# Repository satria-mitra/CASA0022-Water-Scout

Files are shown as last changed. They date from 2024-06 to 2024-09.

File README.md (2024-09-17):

<h1 align="center">Water Scout: A LoRaWAN-Based Water Height Monitoring and Visualization System for Urban Waterways</h1>

A dissertation for an [MSc Connected Environments](https://www.ucl.ac.uk/prospective-students/graduate/taught-degrees/connected-environments-msc)
<p>Centre for Advanced Spatial Analysis, Bartlett Faculty of the Built Environment</p>
<p>University College London </p>

##

This project utilised an Arduino 1310 with LoRaWAN communication and Ultrasonic sensor to monitor the water level of the River Lea that flows below the House Mill. The data observed then transmitted to The Things Network and published to MQTT Client. A 3D visualisation web page using WebXR was built to display the water level of The House Mill in 3D scene. The House Mill was created by [Dr. Gai Jorayev ](https://www.ucl.ac.uk/archaeology/people/gai-jorayev) and published on [Sketchfab](https://sketchfab.com/3d-models/house-mill-in-2019-c87dd07ab29f474aa491c88bc6b4956f). [The 3D visualisations web page](https://casa-0022-water-scout.vercel.app/) was hosted in the cloud for accessibility

| Water Scout | 3D Visualisations |
| :---: | :---: |
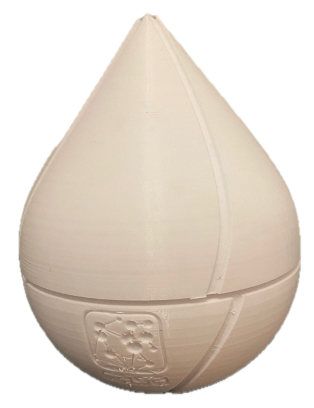
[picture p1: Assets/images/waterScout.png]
Water Scout device
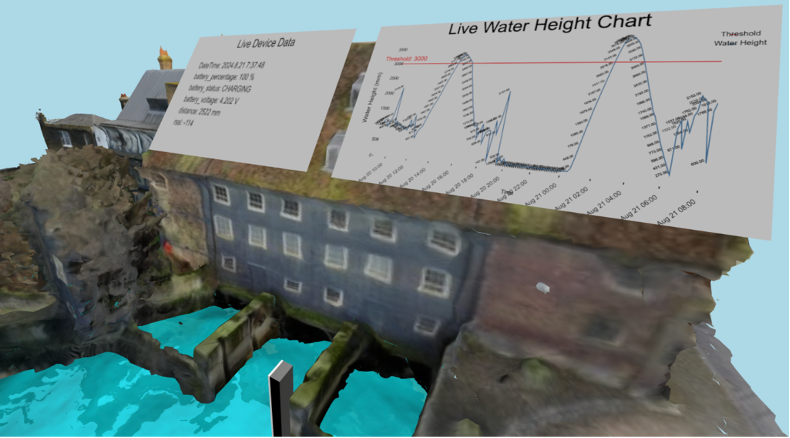
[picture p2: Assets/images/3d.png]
3D Visualisations
|  |  |

## Repository Content Summary

1. **3D Parts**

   This folder includes the 3D printed parts, namely Fusion360 project files and STLs for the enclosures and the 3D objects for the Data Table.

   - [Water Scout Enclosure](</3D Parts/Enclosure>)
   - [Solar Panel](</3D Parts/Solar Panel/>)

2. **Arduino**

   Includes code during calibration mode, and Water Scout device

   - [DYP-A01](/Arduino/DYP-A01)

3. **Schematics**

   The final schematics including PCB Gerber file used for this project. 
   
4. **Docs**

   This folder holds the page for the Water Scout web pages, including device introduction, 3D Visualisation page and VR mode for Connected Environment exhibition

5. **Dashboard**

   The configuration file for Node Red, Influxdb and Grafana 

6. **Supporting Documents**

   The extra files from the dissertation report, including Lab Testing, Deployment Test, and analysis

## Project Overview

<p align="center">Final prototype</p>

<p align="center">

</p>

## Building

### Used components and tools

Hardware:

* [Arduino MKR WAN 1310](https://docs.arduino.cc/hardware/mkr-wan-1310): microcontroller with LoRa connectivity.
* [DYP-A01](https://www.dypcn.com/high-performance-ultrasonic-precision-rangefinder-dyp-a01-product/): a weatherproof humidity and temperature sensor.
* [Adafruit Solar Charger](https://www.adafruit.com/product/4755): a solar charger module
* [Adafruit Lipo Battery Gauge](https://www.adafruit.com/product/5580)
* [Solar panel](https://coolcomponents.co.uk/products/solar-panel-1-watt): 1 Watt, 10x80 cm.
* 2000 mA 3.7v battery

Software:

 - [InfluxDB](https://www.influxdata.com/)
 - [Telegraf](https://www.influxdata.com/time-series-platform/telegraf/)
 - [Grafana](https://grafana.com/)
 - [Docker Compose](https://docs.docker.com/compose/)

All the software applications are packed into one using Docker

## Results

#### The 3D Visualisations

<p align="center">3D Visualisations scene</p>

<p align="center">

</p>

Click here for [3D Visualisations](https://casa-0022-water-scout.vercel.app/visualisation.html)

#### VR Mode for exhibition

<p align="center">3D Visualisations scene</p>

<p align="center">

</p>

Click here for [VR Mode](https://casa-0022-water-scout.vercel.app/arjs.html)

## Credits

This project was built with inspiration and support from several open-source projects and contributions.

Special thanks to [CASA CE](https://github.com/ucl-casa-ce) team especially for the [Artes](https://github.com/ucl-casa-ce/artes) repository which was instrumental in creating the VR mode for the Water Scout project. Portions of the code for the VR mode were adapted and modified from his project.

Additionally, thanks to the open-source communities and contributors behind the following software and tools, which were essential in the development of this project:

- Arduino
- The Things Network
- InfluxDB
- Grafana
- Docker

## License

###### The software side is licensed under MIT License

```
MIT License

Permission is hereby granted, free of charge, to any person obtaining a copy
of this software and associated documentation files (the "Software"), to deal
in the Software without restriction, including without limitation the rights
to use, copy, modify, merge, publish, distribute, sublicense, and/or sell
copies of the Software, and to permit persons to whom the Software is
furnished to do so, subject to the following conditions:

The above copyright notice and this permission notice shall be included in all
copies or substantial portions of the Software.

THE SOFTWARE IS PROVIDED "AS IS", WITHOUT WARRANTY OF ANY KIND, EXPRESS OR
IMPLIED, INCLUDING BUT NOT LIMITED TO THE WARRANTIES OF MERCHANTABILITY,
FITNESS FOR A PARTICULAR PURPOSE AND NONINFRINGEMENT. IN NO EVENT SHALL THE
AUTHORS OR COPYRIGHT HOLDERS BE LIABLE FOR ANY CLAIM, DAMAGES OR OTHER
LIABILITY, WHETHER IN AN ACTION OF CONTRACT, TORT OR OTHERWISE, ARISING FROM,
OUT OF OR IN CONNECTION WITH THE SOFTWARE OR THE USE OR OTHER DEALINGS IN THE
SOFTWARE.
```

###### The hardware side is licensed under CERN License

```
This documentation describes Open Hardware and is licensed under the CERN OHL v. 1.2.

You may redistribute and modify this documentation under the terms of the CERN OHL v.1.2. (http://ohwr.org/cernohl). This documentation is distributed WITHOUT ANY EXPRESS OR IMPLIED WARRANTY, INCLUDING OF MERCHANTABILITY, SATISFACTORY QUALITY AND FITNESS FOR A PARTICULAR PURPOSE. Please see the CERN OHL v.1.2 for applicable conditions
```

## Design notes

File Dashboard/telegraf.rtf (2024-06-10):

# Telegraf Configuration

# Global settings - you don't need to edit these #

# Global tags can be specified here in key="value" format.

[global_tags]

# Configuration for telegraf agent

[agent]
## Default data collection interval for all inputs

## For the plant monitor demo you dont need to change any these settings

interval = "10s"
round_interval = true
metric_batch_size = 1000
metric_buffer_limit = 10000
collection_jitter = "0s"
flush_interval = "10s"
flush_jitter = "0s"
precision = ""
debug = false
quiet = false
logfile = ""
## Override default hostname, if empty use os.Hostname()

hostname = ""
## If set to true, do no set the "host" tag in the telegraf agent.

omit_hostname = false

# OUTPUT PLUGINS #

[[outputs.influxdb_v2]]
urls = ["http://127.0.0.1:8086"]
## Token for authentication.

token = "A9q1_9cbwyPD3nAienTWf8Uuuoo83Wz6qguXdMlR4iapjWbsfOyw_JCQZXwPrnQ2FdWYLl-OxhJSIwsnli-82A=="
## Organization is the name of the organization you wish to write to; must exist.

organization = "casa"
## Destination bucket to write into.

bucket = "rasp-pi"

[[outputs.influxdb_v2]]
urls = ["http://127.0.0.1:8086"]
## Token for authentication.

token = "A9q1_9cbwyPD3nAienTWf8Uuuoo83Wz6qguXdMlR4iapjWbsfOyw_JCQZXwPrnQ2FdWYLl-OxhJSIwsnli-82A=="
## Organization is the name of the organization you wish to write to; must exist.

organization = "casa"
## Destination bucket to write into.

bucket = "mqtt-data"

# INPUT PLUGINS #

# Read metrics about cpu usage

[[inputs.cpu]]
## Whether to report per-cpu stats or not

percpu = true
## Whether to report total system cpu stats or not

totalcpu = true
## If true, collect raw CPU time metrics.

collect_cpu_time = false
## If true, compute and report the sum of all non-idle CPU states.

report_active = false

[[inputs.disk]]
## By default stats will be gathered for all mount points.

## Set mount_points will restrict the stats to only the specified mount points.

# mount_points = ["/"]

## Ignore mount points by filesystem type.

ignore_fs = ["tmpfs", "devtmpfs", "devfs", "overlay", "aufs", "squashfs"]
[[inputs.diskio]]
[[inputs.mem]]
[[inputs.net]]
[[inputs.processes]]
[[inputs.swap]]
[[inputs.system]]

[[inputs.exec]]
commands = ["/usr/bin/vcgencmd measure_temp"]
name_override = "temperature_gpu"
data_format = "grok"
grok_patterns = ["%{NUMBER:value:float}"]

[[inputs.temp]]

# SERVICE INPUT PLUGINS #

# Read metrics from MQTT topic(s)

#THING NETWORK META DATA#

[[inputs.mqtt_consumer]]
alias = "thing_network_consumer"
name_override = "thing_network"
servers = ["tcp://eu1.cloud.thethings.network:1883"]
topics = ["#"]
max_undelivered_messages = 1

username = "${THING_USERNAME}"
password = "${THING_API_KEY}"
data_format = "json_v2"

[[inputs.mqtt_consumer.json_v2]]
[[inputs.mqtt_consumer.json_v2.tag]]
path = "@this.end_device_ids.device_id"

[[inputs.mqtt_consumer.json_v2.object]]
path = "end_device_ids"
disable_prepend_keys = true

[[inputs.mqtt_consumer.json_v2.object]]
path = "uplink_message"
disable_prepend_keys = true
excluded_keys = ["time", "timestamp"]

[[inputs.mqtt_consumer.json_v2.object]]
path = "uplink_message.rx_metadata"
disable_prepend_keys = true
excluded_keys = ["time", "timestamp"]

#PLANT BUDDY DATA#

[[inputs.mqtt_consumer]]
alias = "thing_network_consumer2"
name_override = "sensor_data"

servers = ["tcp://eu1.cloud.thethings.network:1883"]
topics = ["#"]

username = "${THING_USERNAME}"
password = "${THING_API_KEY}"

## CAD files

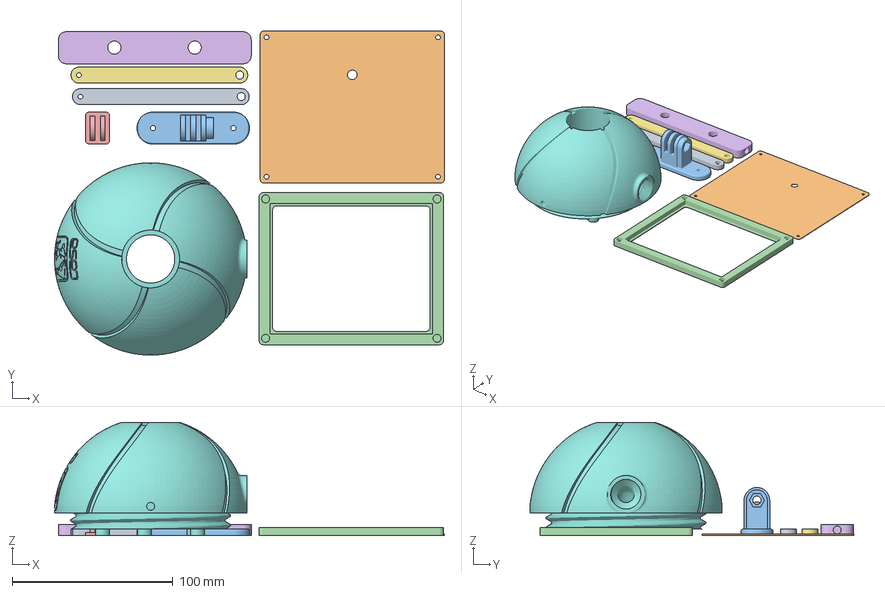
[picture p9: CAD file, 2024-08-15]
3D Parts/device.3mf
242.6 x 201.7 x 70.5 mm
arm.stl x 2
back_cover.stl
bracket_go_pro.stl
front_cover.stl
two_way_bracket.stl
bar.stl
bot_v3.stl

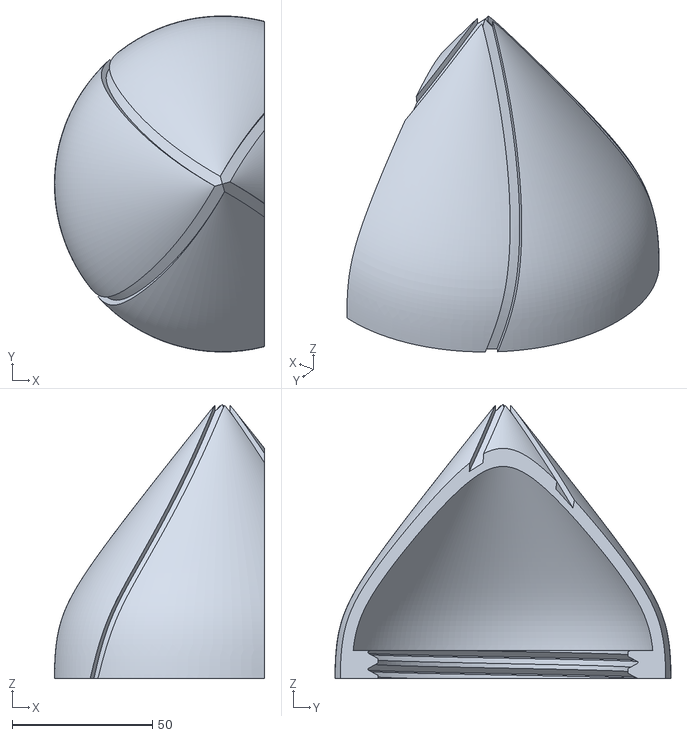
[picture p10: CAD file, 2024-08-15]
3D Parts/Encsloure/top_part_half.stl
74.8 x 119.6 x 97.5

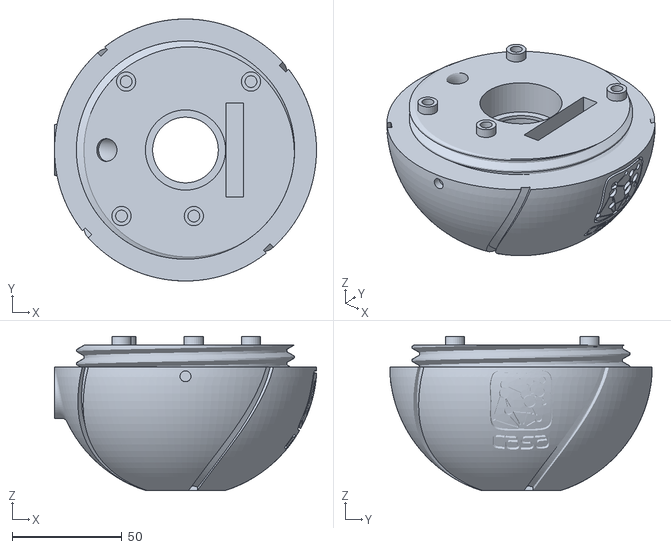
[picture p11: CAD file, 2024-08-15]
3D Parts/Encsloure/bot_v3.stl
119.6 x 119.6 x 70.5

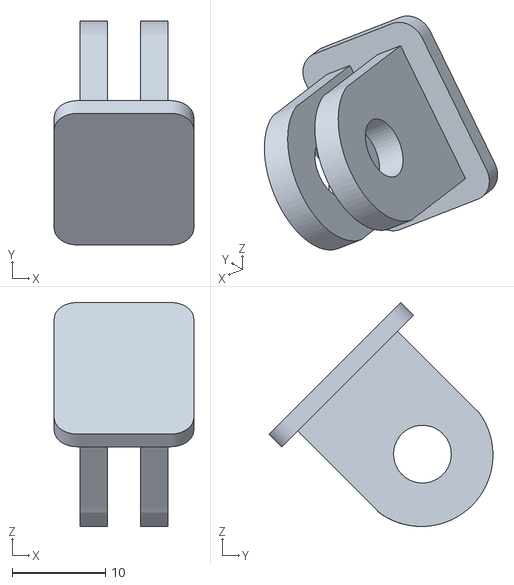
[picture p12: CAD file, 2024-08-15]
3D Parts/Solar Panel/Body1.stl
15.0 x 24.1 x 24.1

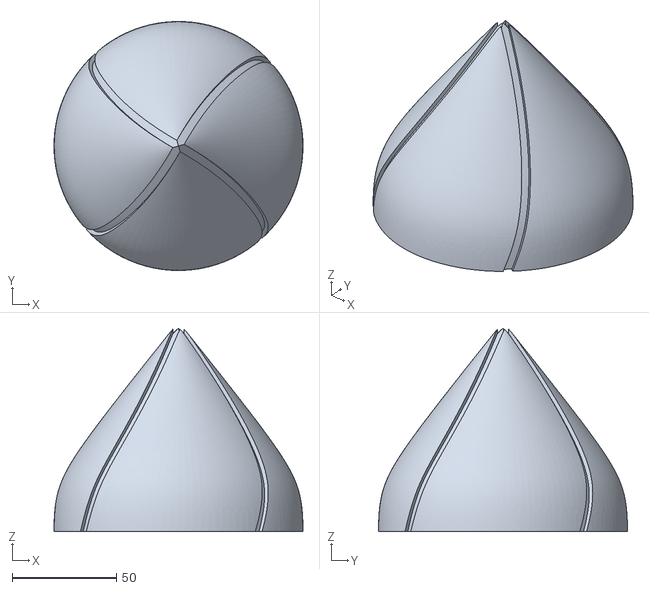
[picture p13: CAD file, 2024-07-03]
3D Parts/Encsloure/top_v2.stl
119.6 x 119.6 x 97.5

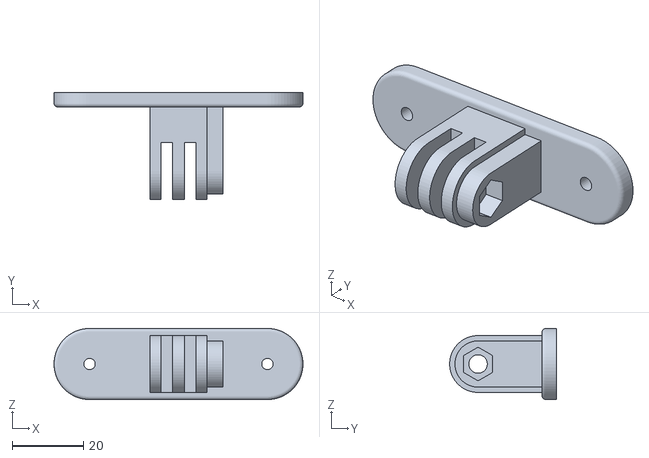
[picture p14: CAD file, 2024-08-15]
3D Parts/Solar Panel/bracket_go_pro.stl
70.0 x 30.0 x 20.0

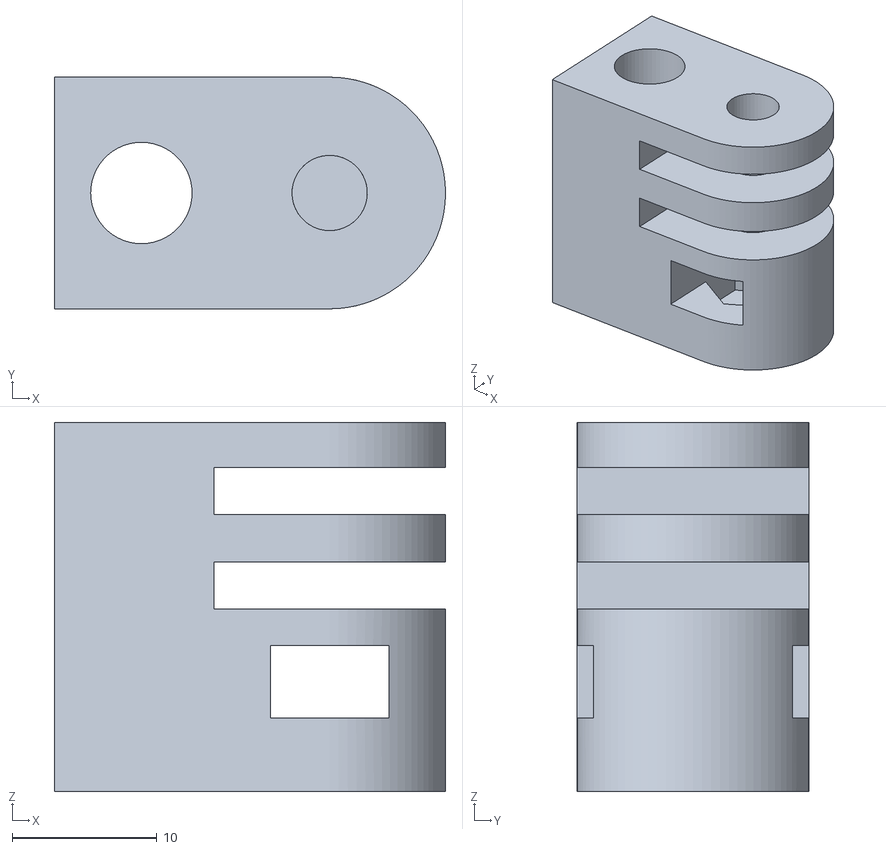
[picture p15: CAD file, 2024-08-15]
3D Parts/Solar Panel/solar_panel_trimount.stl
27.0 x 16.0 x 25.5

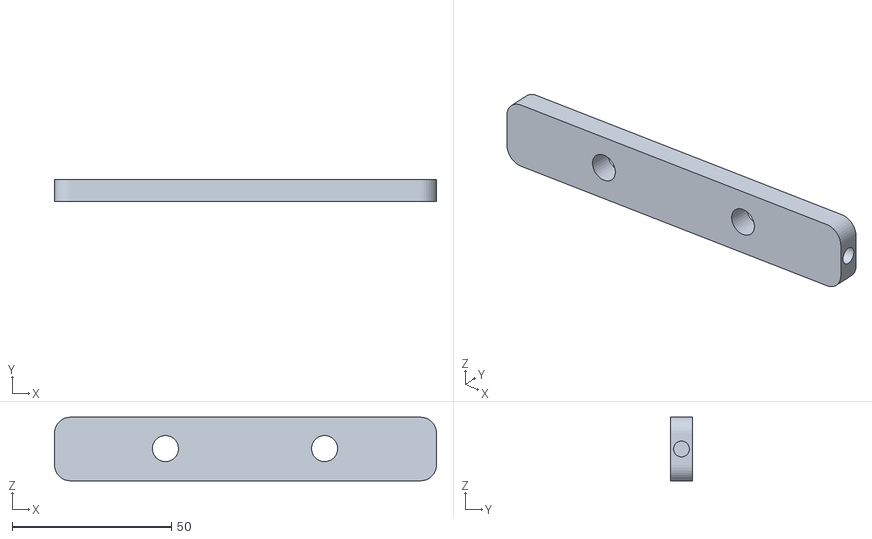
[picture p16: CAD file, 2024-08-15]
3D Parts/Solar Panel/bar.stl
120.0 x 7.00 x 20.0

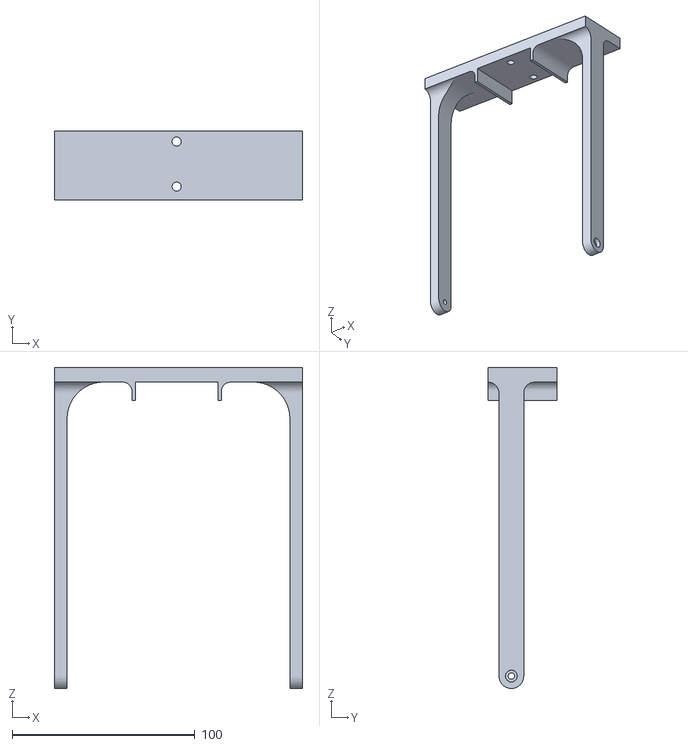
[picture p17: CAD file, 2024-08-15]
3D Parts/Solar Panel/device_bracket.stl
136.0 x 37.8 x 175.8

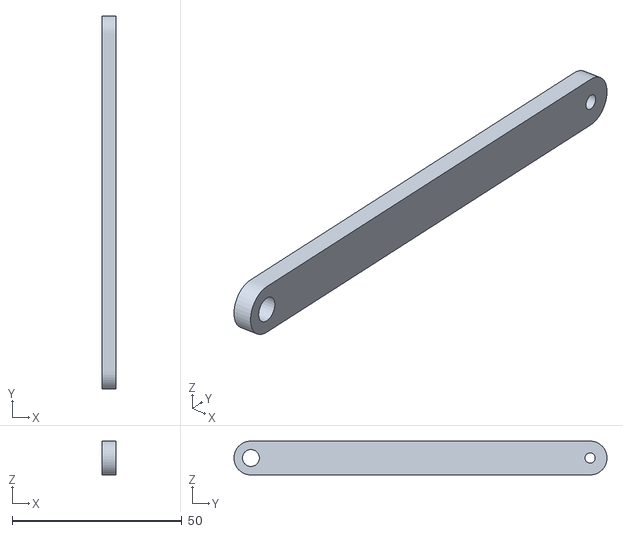
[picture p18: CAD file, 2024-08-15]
3D Parts/Solar Panel/arm.stl
4.00 x 110.0 x 10.0

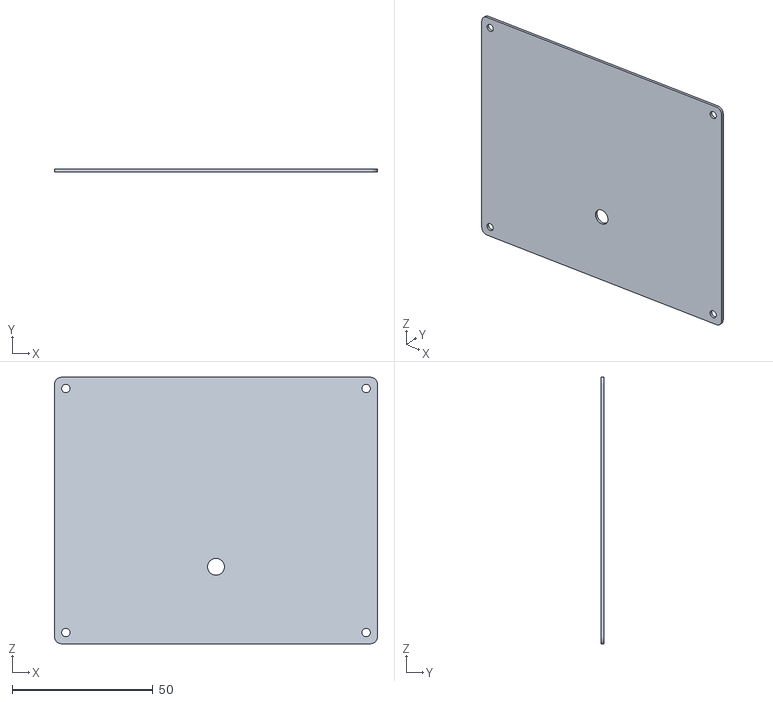
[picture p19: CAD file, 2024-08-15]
3D Parts/Solar Panel/back_cover.stl
114.7 x 1.00 x 94.7

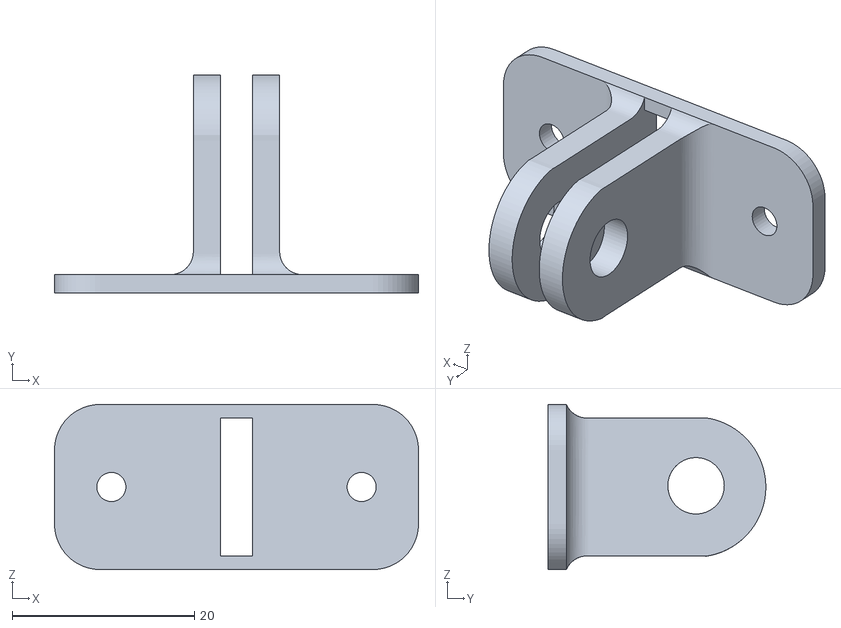
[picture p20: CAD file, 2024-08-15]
3D Parts/Solar Panel/back_bracket_v2.stl
40.0 x 23.9 x 18.1

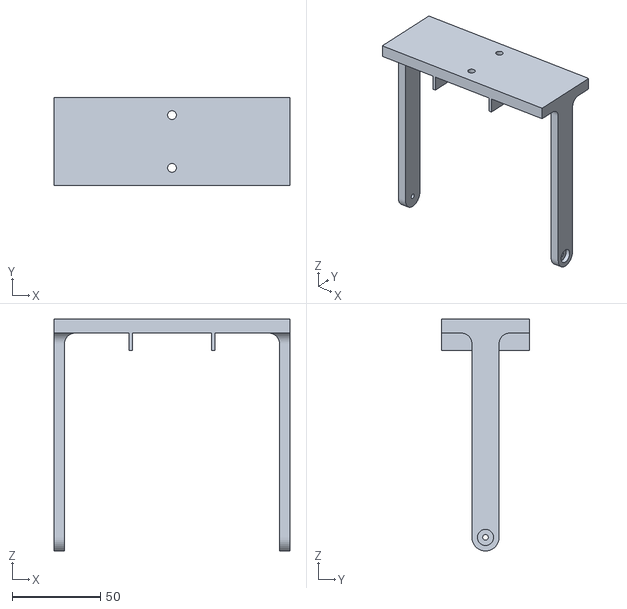
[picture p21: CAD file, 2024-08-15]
3D Parts/Solar Panel/device_arm.stl
134.0 x 50.0 x 131.7

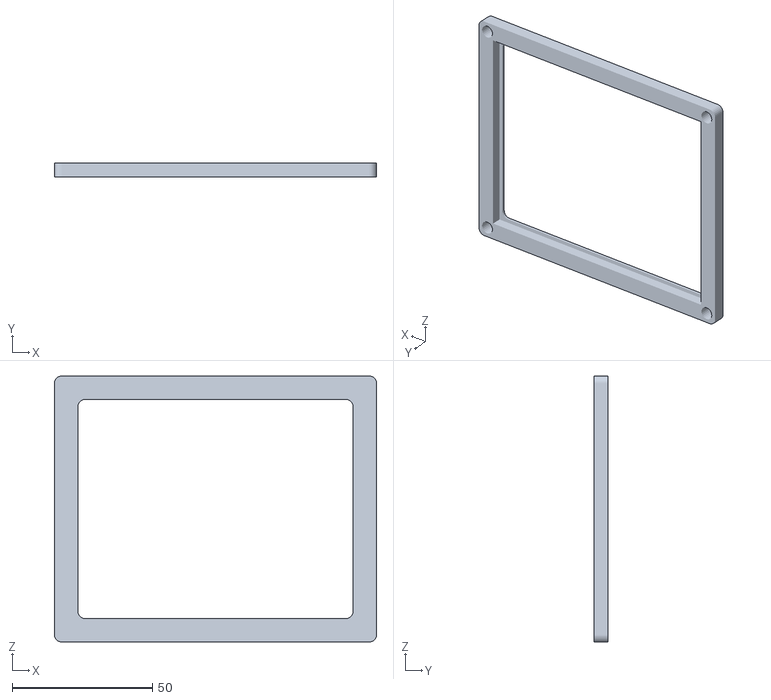
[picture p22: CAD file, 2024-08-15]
3D Parts/Solar Panel/front_cover.stl
114.7 x 5.00 x 94.7

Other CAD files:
3D Parts/Solar Panel/two_way_bracket.stl
3D Parts/Solar Panel/back_bracket v1.stl

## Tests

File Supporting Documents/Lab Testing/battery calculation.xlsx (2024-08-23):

State | Average Duration (seconds) | Average Current draws (mA) | Sum mA | Duty Cycle | Avg Consumption | 850 mAh Battery Life (days) | 1000 mAh Battery life (days) | 2000 mAh Battery Life (days)
Sensor Reading | 3 | 13 | 39 | 1 | 1.462 | 24.22 | 28.50 | 28.50
LoRA Transmitting | 4 | 5.34 | 21.36 | 5 | 0.696 | 50.91 | 59.90 | 59.90
LoRA Receiving | 1 | 1.16 | 1.16 | 10 | 0.600 | 59.05 | 69.47 | 69.47
Deep sleep Mode | 52 | 0.504 | 26.208 | 15 | 0.568 | 62.37 | 73.37 | 73.37
Sum | 60 |  | 87.728
Avg |  |  | 1.462133333
Sensor Reading | 3 | 13 | 39
LoRA Transmitting | 4 | 5.34 | 21.36
LoRA Receiving | 1 | 1.16 | 1.16
Deep sleep Mode | 292 | 0.504 | 147.168
Sum | 300 |  | 208.688
Avg |  |  | 0.6956266667
Sensor Reading | 3 | 13 | 39
LoRA Transmitting | 4 | 5.34 | 21.36
LoRA Receiving | 1 | 1.16 | 1.16
Deep sleep Mode | 592 | 0.504 | 298.368
 | 600 |  | 359.888
 |  |  | 0.5998133333
Sensor Reading | 3 | 13 | 39
LoRA Transmitting | 4 | 5.34 | 21.36
LoRA Receiving | 1 | 1.16 | 1.16
Deep sleep Mode | 892 | 0.504 | 449.568
 | 900 |  | 511.088
 |  |  | 0.5678755556

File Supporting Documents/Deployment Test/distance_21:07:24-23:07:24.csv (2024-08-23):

Time | distance
21/07/24 04:10 | 1800
21/07/24 04:20 | 1800
21/07/24 04:30 | 1780
21/07/24 04:40 | 1800
21/07/24 04:50 | 1800
21/07/24 05:00 | 1773
21/07/24 05:10 | 1647
21/07/24 05:20 | 1532
21/07/24 05:30 | 1438
21/07/24 05:40 | 1401
21/07/24 05:50 | 1409
21/07/24 06:00 | 1465
21/07/24 06:10 | 1530
21/07/24 06:20 | 1635
21/07/24 06:30 | 1778
21/07/24 06:40 | 1789
21/07/24 06:50 | 1790
21/07/24 07:00 | 1795
21/07/24 07:10 | 1774
21/07/24 07:20 | 1790
21/07/24 07:30 | 1799
21/07/24 07:40 | 1796
21/07/24 07:50 | 1788
21/07/24 08:00 | 1773
21/07/24 08:10 | 1782
21/07/24 08:20 | 1785
21/07/24 08:30 | 1776
21/07/24 08:40 | 1792
21/07/24 08:50 | 1778
21/07/24 09:00 | 1777
21/07/24 09:10 | 1783
21/07/24 09:20 | 1800
21/07/24 09:35 | 1775
21/07/24 09:40 | 1781
21/07/24 09:50 | 1774
21/07/24 10:00 | 1798
21/07/24 10:10 | 1793
21/07/24 10:20 | 1780
21/07/24 10:30 | 1775
21/07/24 10:40 | 1770
21/07/24 10:50 | 1790
21/07/24 11:00 | 1785
21/07/24 11:10 | 1788
21/07/24 11:20 | 1781
21/07/24 11:30 | 1778
21/07/24 11:40 | 1794
21/07/24 11:50 | 1782
21/07/24 12:00 | 1786
21/07/24 12:15 | 1777
21/07/24 12:20 | 1773
21/07/24 12:30 | 1800
21/07/24 12:40 | 1777
21/07/24 12:50 | 1796
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

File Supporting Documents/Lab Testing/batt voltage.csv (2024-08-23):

Time | battery_voltage
07/06/2024 16:00 | 4.198
07/06/2024 16:10 | 4.197
07/06/2024 16:20 | 4.197
07/06/2024 16:30 | 4.197
07/06/2024 16:40 | 4.197
07/06/2024 16:50 | 4.197
07/06/2024 17:00 | 4.196
07/06/2024 17:10 | 4.196
07/06/2024 17:20 | 4.197
07/06/2024 17:30 | 4.195
07/06/2024 17:40 | 4.197
07/06/2024 17:50 | 4.193
07/06/2024 18:00 | 4.196
07/06/2024 18:10 | 4.197
07/06/2024 18:20 | 4.195
07/06/2024 18:30 | 4.197
07/06/2024 18:40 | 4.197
07/06/2024 18:50 | 4.197
07/06/2024 19:00 | 4.197
07/06/2024 19:10 | 4.195
07/06/2024 19:20 | 4.196
07/06/2024 19:30 | 4.196
07/06/2024 19:40 | 4.193
07/06/2024 19:50 | 4.196
07/06/2024 20:00 | 4.196
07/06/2024 20:10 | 4.196
07/06/2024 20:20 | 4.195
07/06/2024 20:30 | 4.195
07/06/2024 20:40 | 4.193
07/06/2024 20:50 | 4.195
07/06/2024 21:00 | 4.195
07/06/2024 21:10 | 4.193
07/06/2024 21:20 | 4.193
07/06/2024 21:30 | 4.195
07/06/2024 21:40 | 4.193
07/06/2024 21:50 | 4.193
07/06/2024 22:00 | 4.193
07/06/2024 22:10 | 4.195
07/06/2024 22:20 | 4.196
07/06/2024 22:30 | 4.196
07/06/2024 22:40 | 4.197
07/06/2024 22:50 | 4.197
07/06/2024 23:00 | 4.198
07/06/2024 23:10 | 4.2
07/06/2024 23:20 | 4.202
07/06/2024 23:30 | 4.201
07/06/2024 23:40 | 4.2
07/06/2024 23:50 | 4.2
08/06/2024 00:00 | 4.2
08/06/2024 00:10 | 4.198
08/06/2024 00:20 | 4.198
08/06/2024 00:30 | 4.2
08/06/2024 00:40 | 4.2
08/06/2024 00:50 | 4.198
08/06/2024 01:00 | 4.2
08/06/2024 01:10 | 4.2
08/06/2024 01:20 | 4.198
08/06/2024 01:30 | 4.201
08/06/2024 01:40 | 4.198
08/06/2024 01:50 | 4.2
08/06/2024 02:00 | 4.198
08/06/2024 02:10 | 4.2
08/06/2024 02:20 | 4.2
08/06/2024 02:30 | 4.197
08/06/2024 02:40 | 4.2
08/06/2024 02:50 | 4.2
08/06/2024 03:00 | 4.198
08/06/2024 03:10 | 4.2
08/06/2024 03:20 | 4.2
08/06/2024 03:30 | 4.2
08/06/2024 03:40 | 4.198
08/06/2024 03:50 | 4.2
08/06/2024 04:00 | 4.198
08/06/2024 04:10 | 4.2
08/06/2024 04:20 | 4.2
08/06/2024 04:30 | 4.198
08/06/2024 04:40 | 4.2
08/06/2024 04:50 | 4.2
08/06/2024 05:00 | 4.2
08/06/2024 05:10 | 4.2
08/06/2024 05:20 | 4.198
08/06/2024 05:30 | 4.198
08/06/2024 05:40 | 4.198
08/06/2024 05:50 | 4.197
08/06/2024 06:00 | 4.197
08/06/2024 06:10 | 4.198
08/06/2024 06:20 | 4.2
08/06/2024 06:30 | 4.198
08/06/2024 06:40 | 4.198
08/06/2024 06:50 | 4.201
08/06/2024 07:00 | 4.2
08/06/2024 07:10 | 4.198
08/06/2024 07:20 | 4.2
08/06/2024 07:30 | 4.2
08/06/2024 07:40 | 4.198
08/06/2024 07:50 | 4.198
08/06/2024 08:00 | 4.2
08/06/2024 08:10 | 4.197
08/06/2024 08:20 | 4.2
08/06/2024 08:30 | 4.198
08/06/2024 08:40 | 4.2
08/06/2024 08:50 | 4.2
08/06/2024 09:00 | 4.198
08/06/2024 09:10 | 4.2
08/06/2024 09:20 | 4.2
08/06/2024 09:30 | 4.201
08/06/2024 09:40 | 4.2
08/06/2024 09:50 | 4.2
08/06/2024 10:00 | 4.201
08/06/2024 10:10 | 4.201
08/06/2024 10:20 | 4.201
08/06/2024 10:30 | 4.201
08/06/2024 10:40 | 4.202
08/06/2024 10:50 | 4.201
08/06/2024 11:00 | 4.2
08/06/2024 11:10 | 4.2
08/06/2024 11:20 | 4.2
08/06/2024 11:30 | 4.2
08/06/2024 11:40 | 4.198
08/06/2024 11:50 | 4.2
08/06/2024 12:00 | 4.201
08/06/2024 12:10 | 4.198
08/06/2024 12:20 | 4.198
08/06/2024 12:30 | 4.2
08/06/2024 12:40 | 4.196
08/06/2024 12:50 | 4.198
08/06/2024 13:00 | 4.198
08/06/2024 13:10 | 4.197
08/06/2024 13:20 | 4.2
08/06/2024 13:30 | 4.197
08/06/2024 13:40 | 4.2
08/06/2024 13:50 | 4.198
08/06/2024 14:00 | 4.2
08/06/2024 14:10 | 4.197
08/06/2024 14:20 | 4.2
08/06/2024 14:30 | 4.196
08/06/2024 14:40 | 4.198
08/06/2024 14:50 | 4.198
08/06/2024 15:00 | 4.197
08/06/2024 15:10 | 4.198
08/06/2024 15:20 | 4.198
08/06/2024 15:30 | 4.198
08/06/2024 15:40 | 4.197
08/06/2024 15:50 | 4.198
08/06/2024 16:00 | 4.197
08/06/2024 16:10 | 4.197
08/06/2024 16:20 | 4.193
08/06/2024 16:30 | 4.198
08/06/2024 16:40 | 4.198
08/06/2024 16:50 | 4.198
08/06/2024 17:00 | 4.196
08/06/2024 17:10 | 4.197
08/06/2024 17:20 | 4.198
08/06/2024 17:30 | 4.196
08/06/2024 17:40 | 4.197
08/06/2024 17:50 | 4.196
08/06/2024 18:00 | 4.197
08/06/2024 18:10 | 4.192
08/06/2024 18:20 | 4.196
08/06/2024 18:30 | 4.196
08/06/2024 18:40 | 4.197
08/06/2024 18:50 | 4.197
08/06/2024 19:00 | 4.195
08/06/2024 19:10 | 4.195
08/06/2024 19:20 | 4.196
08/06/2024 19:30 | 4.196
08/06/2024 19:40 | 4.195
08/06/2024 19:50 | 4.196
08/06/2024 20:00 | 4.19
08/06/2024 20:10 | 4.196
08/06/2024 20:20 | 4.195
08/06/2024 20:30 | 4.195
08/06/2024 20:40 | 4.196
08/06/2024 20:50 | 4.196
08/06/2024 21:00 | 4.195
08/06/2024 21:10 | 4.195
08/06/2024 21:20 | 4.195
08/06/2024 21:30 | 4.193
08/06/2024 21:40 | 4.195
08/06/2024 21:50 | 4.192
08/06/2024 22:00 | 4.195
08/06/2024 22:10 | 4.195
08/06/2024 22:20 | 4.195
08/06/2024 22:30 | 4.197
08/06/2024 22:40 | 4.196
08/06/2024 22:50 | 4.198
08/06/2024 23:00 | 4.197
08/06/2024 23:10 | 4.198
08/06/2024 23:20 | 4.2
08/06/2024 23:30 | 4.201
08/06/2024 23:40 | 4.197
08/06/2024 23:50 | 4.201
09/06/2024 00:00 | 4.201
09/06/2024 00:10 | 4.2
09/06/2024 00:20 | 4.2
09/06/2024 00:30 | 4.201
09/06/2024 00:40 | 4.197
09/06/2024 00:50 | 4.198
09/06/2024 01:00 | 4.197
09/06/2024 01:10 | 4.2
09/06/2024 01:20 | 4.198
09/06/2024 01:30 | 4.197
09/06/2024 01:40 | 4.201
09/06/2024 01:50 | 4.2
09/06/2024 02:00 | 4.2
09/06/2024 02:10 | 4.201
09/06/2024 02:20 | 4.2
09/06/2024 02:30 | 4.198
09/06/2024 02:40 | 4.2
09/06/2024 02:50 | 4.2
09/06/2024 03:00 | 4.198
09/06/2024 03:10 | 4.2
09/06/2024 03:20 | 4.201
09/06/2024 03:30 | 4.2
09/06/2024 03:40 | 4.198
09/06/2024 03:50 | 4.2
09/06/2024 04:00 | 4.2
09/06/2024 04:10 | 4.198
09/06/2024 04:20 | 4.2
09/06/2024 04:30 | 4.2
09/06/2024 04:40 | 4.198
09/06/2024 04:50 | 4.2
09/06/2024 05:00 | 4.198
09/06/2024 05:10 | 4.2
09/06/2024 05:20 | 4.2
09/06/2024 05:30 | 4.2
09/06/2024 05:40 | 4.198
09/06/2024 05:50 | 4.198
09/06/2024 06:00 | 4.2
09/06/2024 06:10 | 4.198
09/06/2024 06:20 | 4.197
09/06/2024 06:30 | 4.198
09/06/2024 06:40 | 4.2
09/06/2024 06:50 | 4.2
09/06/2024 07:00 | 4.198
09/06/2024 07:10 | 4.198
09/06/2024 07:20 | 4.2
09/06/2024 07:30 | 4.2
09/06/2024 07:40 | 4.2
09/06/2024 07:50 | 4.2
09/06/2024 08:00 | 4.198
09/06/2024 08:10 | 4.201
09/06/2024 08:20 | 4.198
09/06/2024 08:30 | 4.201
09/06/2024 08:40 | 4.198
09/06/2024 08:50 | 4.2
09/06/2024 09:00 | 4.2
09/06/2024 09:10 | 4.2
09/06/2024 09:20 | 4.2
09/06/2024 09:30 | 4.201
09/06/2024 09:40 | 4.2
09/06/2024 09:50 | 4.201
09/06/2024 10:00 | 4.2
09/06/2024 10:10 | 4.198
09/06/2024 10:20 | 4.2
09/06/2024 10:30 | 4.2
09/06/2024 10:40 | 4.202
09/06/2024 10:50 | 4.201
09/06/2024 11:00 | 4.202
09/06/2024 11:10 | 4.201
09/06/2024 11:20 | 4.201
09/06/2024 11:30 | 4.2
09/06/2024 11:40 | 4.201
09/06/2024 11:50 | 4.201
09/06/2024 12:00 | 4.201
09/06/2024 12:10 | 4.2
09/06/2024 12:20 | 4.198
09/06/2024 12:30 | 4.198
09/06/2024 12:40 | 4.198
09/06/2024 12:50 | 4.2
09/06/2024 13:00 | 4.198
09/06/2024 13:10 | 4.197
09/06/2024 13:20 | 4.198
09/06/2024 13:30 | 4.198
09/06/2024 13:40 | 4.198
09/06/2024 13:50 | 4.195
09/06/2024 14:00 | 4.198
09/06/2024 14:10 | 4.198
09/06/2024 14:20 | 4.198
09/06/2024 14:30 | 4.197
09/06/2024 14:40 | 4.198
09/06/2024 14:50 | 4.2
09/06/2024 15:00 | 4.198
09/06/2024 15:10 | 4.197
09/06/2024 15:20 | 4.198
09/06/2024 15:30 | 4.197
09/06/2024 15:40 | 4.192
09/06/2024 15:50 | 4.197

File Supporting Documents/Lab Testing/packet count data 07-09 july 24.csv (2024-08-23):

Time | packet_count
07/06/2024 16:00 | 23
07/06/2024 16:10 | 24
07/06/2024 16:20 | 25
07/06/2024 16:30 | 26
07/06/2024 16:40 | 27
07/06/2024 16:50 | 28
07/06/2024 17:00 | 29
07/06/2024 17:10 | 30
07/06/2024 17:20 | 31
07/06/2024 17:30 | 32
07/06/2024 17:40 | 33
07/06/2024 17:50 | 34
07/06/2024 18:00 | 35
07/06/2024 18:10 | 36
07/06/2024 18:20 | 37
07/06/2024 18:30 | 38
07/06/2024 18:40 | 39
07/06/2024 18:50 | 40
07/06/2024 19:00 | 41
07/06/2024 19:10 | 42
07/06/2024 19:20 | 43
07/06/2024 19:30 | 44
07/06/2024 19:40 | 45
07/06/2024 19:50 | 46
07/06/2024 20:00 | 47
07/06/2024 20:10 | 48
07/06/2024 20:20 | 49
07/06/2024 20:30 | 50
07/06/2024 20:40 | 51
07/06/2024 20:50 | 52
07/06/2024 21:00 | 53
07/06/2024 21:10 | 54
07/06/2024 21:20 | 55
07/06/2024 21:30 | 56
07/06/2024 21:40 | 57
07/06/2024 21:50 | 58
07/06/2024 22:00 | 59
07/06/2024 22:10 | 60
07/06/2024 22:20 | 61
07/06/2024 22:30 | 62
07/06/2024 22:40 | 63
07/06/2024 22:50 | 64
07/06/2024 23:00 | 65
07/06/2024 23:10 | 66
07/06/2024 23:20 | 67
07/06/2024 23:30 | 68
07/06/2024 23:40 | 69
07/06/2024 23:50 | 70
08/06/2024 00:00 | 71
08/06/2024 00:10 | 72
08/06/2024 00:20 | 73
08/06/2024 00:30 | 74
08/06/2024 00:40 | 75
08/06/2024 00:50 | 76
08/06/2024 01:00 | 77
08/06/2024 01:10 | 78
08/06/2024 01:20 | 79
08/06/2024 01:30 | 80
08/06/2024 01:40 | 81
08/06/2024 01:50 | 82
08/06/2024 02:00 | 83
08/06/2024 02:10 | 84
08/06/2024 02:20 | 85
08/06/2024 02:30 | 86
08/06/2024 02:40 | 87
08/06/2024 02:50 | 88
08/06/2024 03:00 | 89
08/06/2024 03:10 | 90
08/06/2024 03:20 | 91
08/06/2024 03:30 | 92
08/06/2024 03:40 | 93
08/06/2024 03:50 | 94
08/06/2024 04:00 | 95
08/06/2024 04:10 | 96
08/06/2024 04:20 | 97
08/06/2024 04:30 | 98
08/06/2024 04:40 | 99
08/06/2024 04:50 | 100
08/06/2024 05:00 | 101
08/06/2024 05:10 | 102
08/06/2024 05:20 | 103
08/06/2024 05:30 | 104
08/06/2024 05:40 | 105
08/06/2024 05:50 | 106
08/06/2024 06:00 | 107
08/06/2024 06:10 | 108
08/06/2024 06:20 | 109
08/06/2024 06:30 | 110
08/06/2024 06:40 | 111
08/06/2024 06:50 | 112
08/06/2024 07:00 | 113
08/06/2024 07:10 | 114
08/06/2024 07:20 | 115
08/06/2024 07:30 | 116
08/06/2024 07:40 | 117
08/06/2024 07:50 | 118
08/06/2024 08:00 | 119
08/06/2024 08:10 | 120
08/06/2024 08:20 | 121
08/06/2024 08:30 | 122
08/06/2024 08:40 | 123
08/06/2024 08:50 | 124
08/06/2024 09:00 | 125
08/06/2024 09:10 | 126
08/06/2024 09:20 | 127
08/06/2024 09:30 | 128
08/06/2024 09:40 | 129
08/06/2024 09:50 | 130
08/06/2024 10:00 | 131
08/06/2024 10:10 | 132
08/06/2024 10:20 | 133
08/06/2024 10:30 | 134
08/06/2024 10:40 | 135
08/06/2024 10:50 | 136
08/06/2024 11:00 | 137
08/06/2024 11:10 | 138
08/06/2024 11:20 | 139
08/06/2024 11:30 | 140
08/06/2024 11:40 | 141
08/06/2024 11:50 | 142
08/06/2024 12:00 | 143
08/06/2024 12:10 | 144
08/06/2024 12:20 | 145
08/06/2024 12:30 | 146
08/06/2024 12:40 | 147
08/06/2024 12:50 | 148
08/06/2024 13:00 | 149
08/06/2024 13:10 | 150
08/06/2024 13:20 | 151
08/06/2024 13:30 | 152
08/06/2024 13:40 | 153
08/06/2024 13:50 | 154
08/06/2024 14:00 | 155
08/06/2024 14:10 | 156
08/06/2024 14:20 | 157
08/06/2024 14:30 | 158
08/06/2024 14:40 | 159
08/06/2024 14:50 | 160
08/06/2024 15:00 | 161
08/06/2024 15:10 | 162
08/06/2024 15:20 | 163
08/06/2024 15:30 | 164
08/06/2024 15:40 | 165
08/06/2024 15:50 | 166
08/06/2024 16:00 | 167
08/06/2024 16:10 | 168
08/06/2024 16:20 | 169
08/06/2024 16:30 | 170
08/06/2024 16:40 | 171
08/06/2024 16:50 | 172
08/06/2024 17:00 | 173
08/06/2024 17:10 | 174
08/06/2024 17:20 | 175
08/06/2024 17:30 | 176
08/06/2024 17:40 | 177
08/06/2024 17:50 | 178
08/06/2024 18:00 | 179
08/06/2024 18:10 | 180
08/06/2024 18:20 | 181
08/06/2024 18:30 | 182
08/06/2024 18:40 | 183
08/06/2024 18:50 | 184
08/06/2024 19:00 | 185
08/06/2024 19:10 | 186
08/06/2024 19:20 | 187
08/06/2024 19:30 | 188
08/06/2024 19:40 | 189
08/06/2024 19:50 | 190
08/06/2024 20:00 | 191
08/06/2024 20:10 | 192
08/06/2024 20:20 | 193
08/06/2024 20:30 | 194
08/06/2024 20:40 | 195
08/06/2024 20:50 | 196
08/06/2024 21:00 | 197
08/06/2024 21:10 | 198
08/06/2024 21:20 | 199
08/06/2024 21:30 | 200
08/06/2024 21:40 | 201
08/06/2024 21:50 | 202
08/06/2024 22:00 | 203
08/06/2024 22:10 | 204
08/06/2024 22:20 | 205
08/06/2024 22:30 | 206
08/06/2024 22:40 | 207
08/06/2024 22:50 | 208
08/06/2024 23:00 | 209
08/06/2024 23:10 | 210
08/06/2024 23:20 | 211
08/06/2024 23:30 | 212
08/06/2024 23:40 | 213
08/06/2024 23:50 | 214
09/06/2024 00:00 | 215
09/06/2024 00:10 | 216
09/06/2024 00:20 | 217
09/06/2024 00:30 | 218
09/06/2024 00:40 | 219
09/06/2024 00:50 | 220
09/06/2024 01:00 | 221
09/06/2024 01:10 | 222
09/06/2024 01:20 | 223
09/06/2024 01:30 | 224
09/06/2024 01:40 | 225
09/06/2024 01:50 | 226
09/06/2024 02:00 | 227
09/06/2024 02:10 | 228
09/06/2024 02:20 | 229
09/06/2024 02:30 | 230
09/06/2024 02:40 | 231
09/06/2024 02:50 | 232
09/06/2024 03:00 | 233
09/06/2024 03:10 | 234
09/06/2024 03:20 | 235
09/06/2024 03:30 | 236
09/06/2024 03:40 | 237
09/06/2024 03:50 | 238
09/06/2024 04:00 | 239
09/06/2024 04:10 | 240
09/06/2024 04:20 | 241
09/06/2024 04:30 | 242
09/06/2024 04:40 | 243
09/06/2024 04:50 | 244
09/06/2024 05:00 | 245
09/06/2024 05:10 | 246
09/06/2024 05:20 | 247
09/06/2024 05:30 | 248
09/06/2024 05:40 | 249
09/06/2024 05:50 | 250
09/06/2024 06:00 | 251
09/06/2024 06:10 | 252
09/06/2024 06:20 | 253
09/06/2024 06:30 | 254
09/06/2024 06:40 | 255
09/06/2024 06:50 | 256
09/06/2024 07:00 | 257
09/06/2024 07:10 | 258
09/06/2024 07:20 | 259
09/06/2024 07:30 | 260
09/06/2024 07:40 | 261
09/06/2024 07:50 | 262
09/06/2024 08:00 | 263
09/06/2024 08:10 | 264
09/06/2024 08:20 | 265
09/06/2024 08:30 | 266
09/06/2024 08:40 | 267
09/06/2024 08:50 | 268
09/06/2024 09:00 | 269
09/06/2024 09:10 | 270
09/06/2024 09:20 | 271
09/06/2024 09:30 | 272
09/06/2024 09:40 | 273
09/06/2024 09:50 | 274
09/06/2024 10:00 | 275
09/06/2024 10:10 | 276
09/06/2024 10:20 | 277
09/06/2024 10:30 | 278
09/06/2024 10:40 | 279
09/06/2024 10:50 | 280
09/06/2024 11:00 | 281
09/06/2024 11:10 | 282
09/06/2024 11:20 | 283
09/06/2024 11:30 | 284
09/06/2024 11:40 | 285
09/06/2024 11:50 | 286
09/06/2024 12:00 | 287
09/06/2024 12:10 | 288
09/06/2024 12:20 | 289
09/06/2024 12:30 | 290
09/06/2024 12:40 | 291
09/06/2024 12:50 | 292
09/06/2024 13:00 | 293
09/06/2024 13:10 | 294
09/06/2024 13:20 | 295
09/06/2024 13:30 | 296
09/06/2024 13:40 | 297
09/06/2024 13:50 | 298
09/06/2024 14:00 | 299
09/06/2024 14:10 | 300
09/06/2024 14:20 | 301
09/06/2024 14:30 | 302
09/06/2024 14:40 | 303
09/06/2024 14:50 | 304
09/06/2024 15:00 | 305
09/06/2024 15:10 | 306
09/06/2024 15:20 | 307
09/06/2024 15:30 | 308
09/06/2024 15:40 | 309
09/06/2024 15:50 | 310

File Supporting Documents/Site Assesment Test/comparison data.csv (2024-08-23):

 | Height at Charlton(m) | Height at Lea Bridge(m) | Height at Tower Pier(m) | Height at House Mill(m)
10:00:00 | 2.51 | 5.86 | -4.62 | 1
10:15:00 | 2.68 | 5.86 | -4.62 | 1.23
10:30:00 | 2.83 | 5.86 | -4.62 | 1.42
10:45:00 | 2.94 | 5.86 | -4.62 | 1.61
11:00:00 | 3.05 | 5.86 | -4.62 | 1.8
11:15:00 | 3.08 | 5.86 | -4.62 | 1.99
11:30:00 | 3.08 | 5.86 | -4.62 | 2.15
11:45:00 | 3.02 | 5.86 | -4.62 | 2.29 | 2.29
12:00:00 | 2.9 | 5.87 | -4.62 | 2.41
12:15:00 | 2.69 | 5.87 | -4.62 | 2.52
12:30:00 | 2.43 | 5.87 | -4.62 | 2.52
12:45:00 | 2.15 | 5.87 | -4.62 | 2.5 |  | 0.15
13:00:00 | 1.85 | 5.87 | -4.62 | 2.44 |  | 0.15
13:15:00 | 1.57 | 5.87 | -4.62 | 2.29 |  | 0.15
13:30:00 | 1.28 | 5.87 | -4.62 | 2.07 |  | 0.15
13:45:00 | 0.99 | 5.87 | -4.62 | 1.81 |  | 0.15
14:00:00 | 0.72 | 5.87 | -4.62 | 1.63 |  | 0.15
14:15:00 | 0.45 | 5.87 | -4.62 | 1.38 |  | 0.15
14:30:00 | 0.19 | 5.87 | -4.62 | 1.15 |  | 0.15
14:45:00 | -0.08 | 5.87 | -4.62 | 1 |  | 0.15
15:00:00 | -0.33 | 5.87 | -4.62 | 1.17 |  | 0.15
15:15:00 | -0.57 | 5.87 | -4.62 | 1.07 |  | 0.15
15:30:00 | -0.77 | 5.87 | -4.62 | 0.98 |  | 0.15
15:45:00 | -0.97 | 5.87 | -4.62 | 1.24 |  | 0.14
16:00:00 | -1.14 | 5.87 | -4.62 | 1 |  | 0.15
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

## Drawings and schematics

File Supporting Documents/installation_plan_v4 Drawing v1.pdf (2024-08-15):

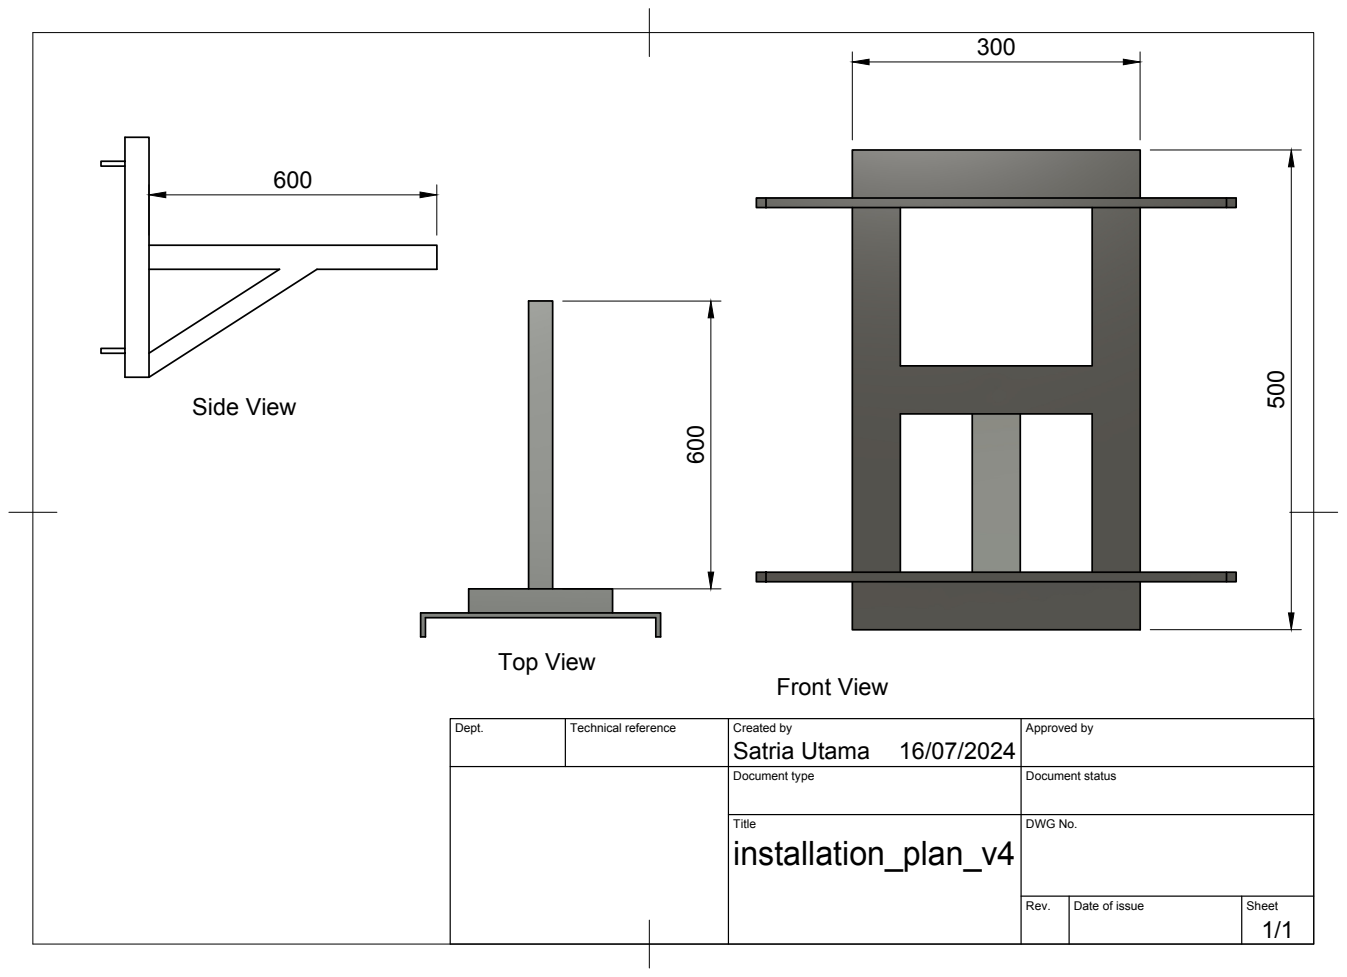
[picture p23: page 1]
Top View; Front View; Side View

Dept. | Technical reference | Created by Satria Utama 16/07/2024 | Approved by

Document type | Document status

Title installation_plan_v4 | DWG No.

Rev. | Date of issue | Sheet 1/1

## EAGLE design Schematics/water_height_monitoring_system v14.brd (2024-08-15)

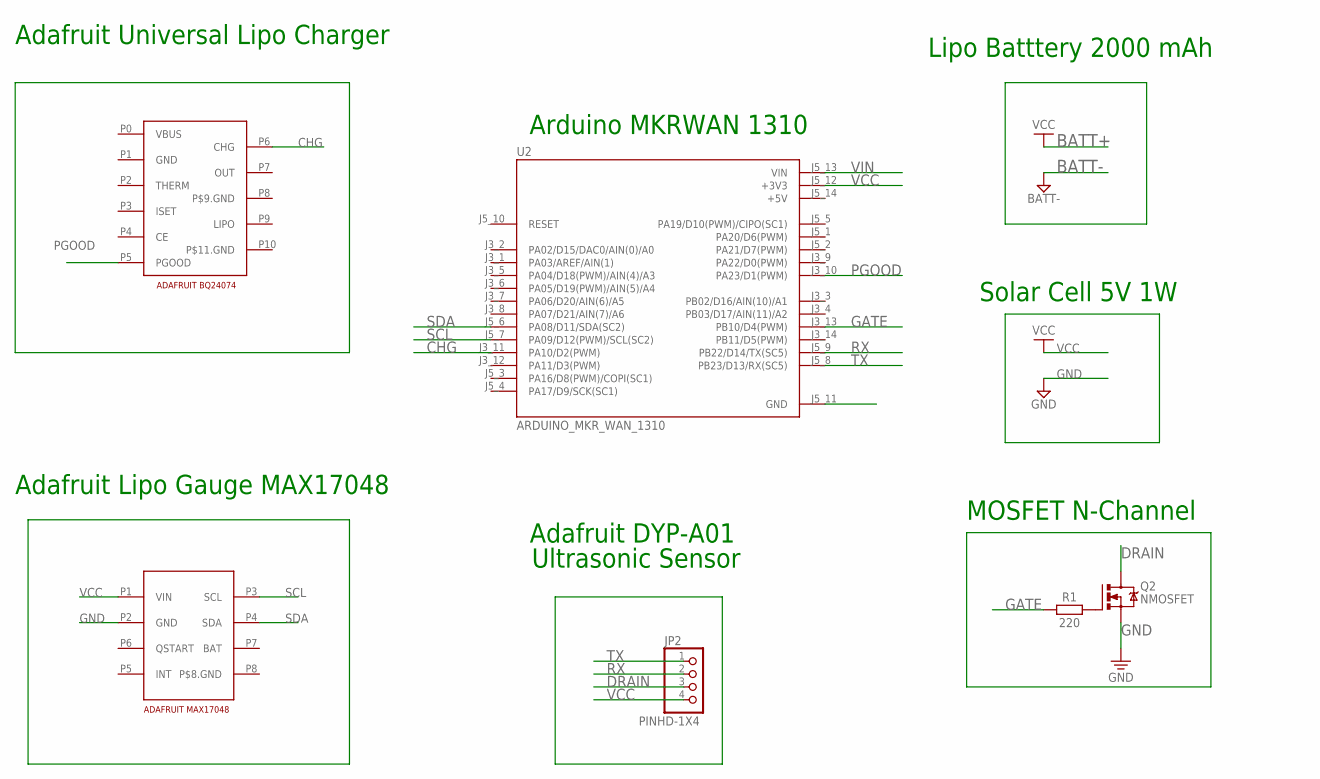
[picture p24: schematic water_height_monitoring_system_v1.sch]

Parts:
JP2: PINHD-1X4; 1X04
Q2: NMOSFET; TO220BV
R1: 220; RESAD724W46L381D178B
U2: ARDUINO_MKR_WAN_1310; BOARD_ARDUINO_MKR_WAN_1310
U$2: ADAFRUIT_BQ24074; BQ24074_MODULE
U$3: ADAFRUIT_MAX17048; MAX17048

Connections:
+5V: U2.J5_14 (+5V)
BAT: U$3.P7 (BAT)
CHG: U2.J3_11 (PA10/D2(PWM)), U$2.P6 (CHG)
DRAIN: JP2.3, Q2.D
GATE: R1.1, U2.J3_13 (PB10/D4(PWM))
LIPO: U$2.P9 (LIPO)
unnamed: Q2.G, R1.2
P$8.GND: U$3.P8 (P$8.GND)
P$9.GND: U$2.P8 (P$9.GND)
P$11.GND: U$2.P10 (P$11.GND)
PGOOD: U2.J3_10 (PA23/D1(PWM)), U$2.P5 (PGOOD)
RX: JP2.2, U2.J5_9 (PB22/D14/TX(SC5))
SCL: U2.J5_7 (PA09/D12(PWM)/SCL(SC2)), U$3.P3 (SCL)
SDA: U2.J5_6 (PA08/D11/SDA(SC2)), U$3.P4 (SDA)
TX: JP2.1, U2.J5_8 (PB23/D13/RX(SC5))
VBUS: U$2.P0 (VBUS)
VCC: JP2.4, U2.J5_12 (+3V3), U$3.P1 (VIN)
VIN: U2.J5_13 (VIN)

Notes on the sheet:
Adafruit Universal Lipo Charger
Adafruit Lipo Gauge MAX17048
Arduino MKRWAN 1310
Lipo Batttery 2000 mAh
Solar Cell 5V 1W
MOSFET N-Channel
Adafruit DYP-A01 Ultrasonic Sensor

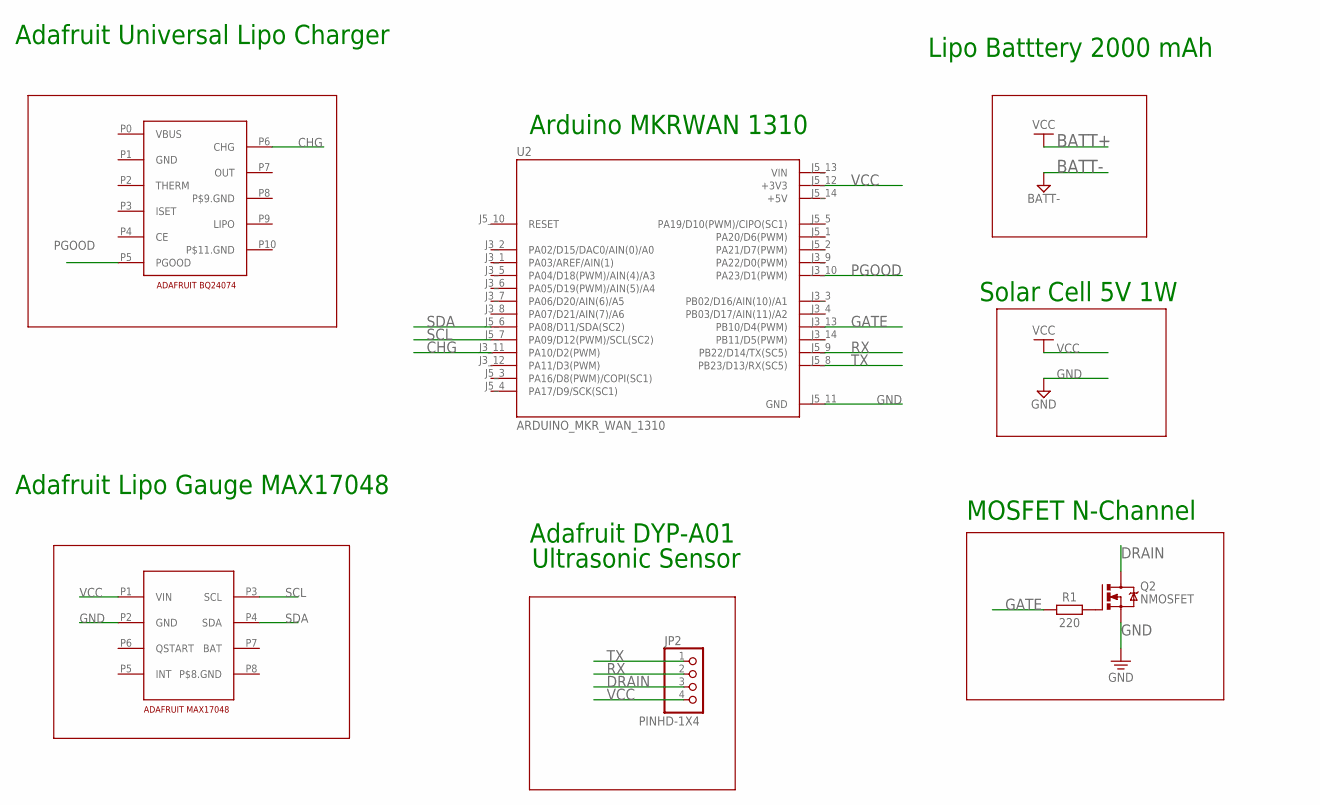
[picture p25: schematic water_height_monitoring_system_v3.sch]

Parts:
JP2: PINHD-1X4; 1X04
Q2: NMOSFET; TO220BV
R1: 220; RESAD724W46L381D178B
U2: ARDUINO_MKR_WAN_1310; BOARD_ARDUINO_MKR_WAN_1310
U$2: ADAFRUIT_BQ24074; BQ24074_MODULE
U$3: ADAFRUIT_MAX17048; MAX17048

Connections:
+5V: U2.J5_14 (+5V)
BAT: U$3.P7 (BAT)
CHG: U2.J3_11 (PA10/D2(PWM)), U$2.P6 (CHG)
DRAIN: JP2.3, Q2.D
GATE: R1.1, U2.J3_13 (PB10/D4(PWM))
LIPO: U$2.P9 (LIPO)
unnamed: Q2.G, R1.2
P$8.GND: U$3.P8 (P$8.GND)
P$9.GND: U$2.P8 (P$9.GND)
P$11.GND: U$2.P10 (P$11.GND)
PGOOD: U2.J3_10 (PA23/D1(PWM)), U$2.P5 (PGOOD)
RX: JP2.2, U2.J5_9 (PB22/D14/TX(SC5))
SCL: U2.J5_7 (PA09/D12(PWM)/SCL(SC2)), U$3.P3 (SCL)
SDA: U2.J5_6 (PA08/D11/SDA(SC2)), U$3.P4 (SDA)
TX: JP2.1, U2.J5_8 (PB23/D13/RX(SC5))
VBUS: U$2.P0 (VBUS)
VCC: JP2.4, U2.J5_12 (+3V3), U$3.P1 (VIN)

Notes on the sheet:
Adafruit Universal Lipo Charger
Adafruit Lipo Gauge MAX17048
Arduino MKRWAN 1310
Lipo Batttery 2000 mAh
Solar Cell 5V 1W
MOSFET N-Channel
Adafruit DYP-A01 Ultrasonic Sensor

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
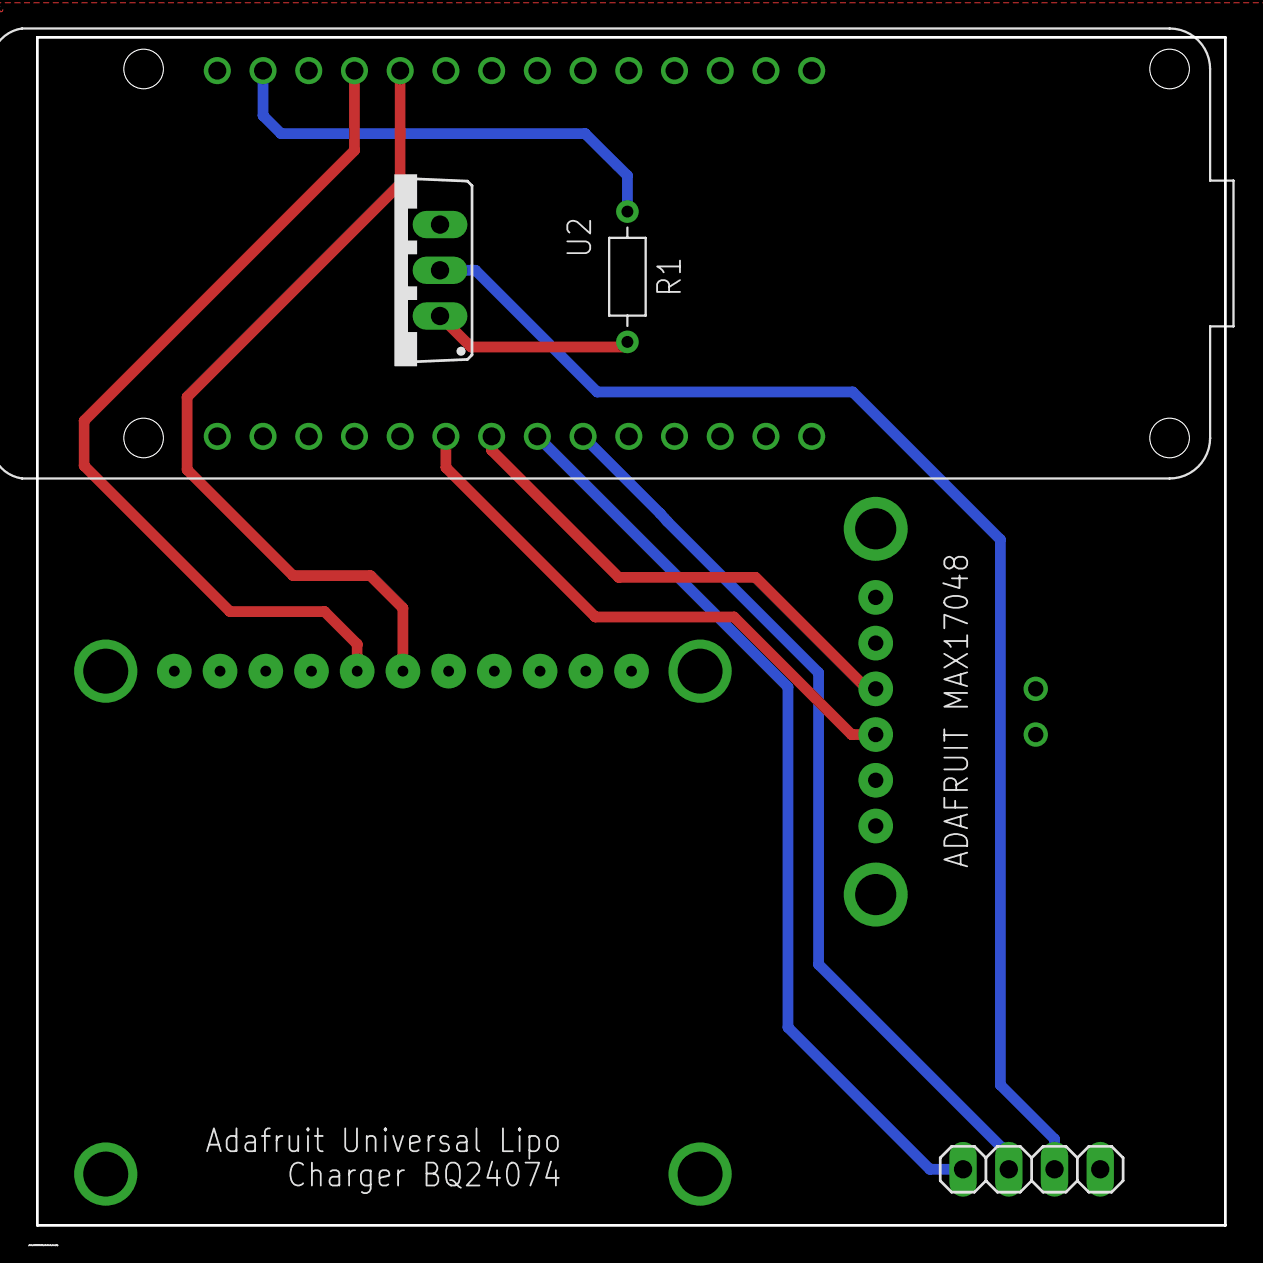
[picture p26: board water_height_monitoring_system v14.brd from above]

Board: 2 copper layers, 66.0 x 66.0 mm, 6 parts (0 on the bottom side), 11 nets.

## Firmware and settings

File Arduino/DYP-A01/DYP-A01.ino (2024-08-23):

/* 
*****************************
Water Height Monitoring
Sensor : Adafruit DYP-A01, Adafruit MAX17048
Developed by : Satria Utama
Last Update : 10 July 2024
V1.8
*****************************

*/

#include <MKRWAN.h>
#include <ArduinoLowPower.h>
#include <Adafruit_MAX1704X.h>
#include "arduino_secrets.h"

/******** Pin, Variables and Class for Solar Charge Controller **********/
// Pin definitions for charge controller
#define PGOOD_PIN 1  // Power Good status pin
#define CHG_PIN 2    // Charge status pin

// Number of samples to take for determining status
#define CHARGE_SAMPLES 10
#define SAMPLE_DELAY 100  // Delay between samples in milliseconds

enum SolarStatus { OFF = 0, ACTIVE = 1 };
enum BatteryStatus { CHARGING = 0, FULL = 1, DRAINING = 2 };

// Variables to hold the status of the solar panel and battery
SolarStatus solar_status = OFF;
BatteryStatus battery_status = DRAINING;

// Class for Solar Charge Controller
class DeviceHealth {
public:
  SolarStatus solar_status;
  BatteryStatus battery_status;
  float batteryVoltage;
  float batteryPercentage;
  void updateDeviceHealth();
  void printDeviceHealth();
};
// Declare class globally
DeviceHealth deviceHealth;


/******** Pin, Variables and Class for Ultrasonic Sensor **********/

const int sensorPowerPin = 4; // Pin to control MOSFET gate
int interval = 55500; //595000;  //; // Interval to wake up (60000 milliseconds or 60 seconds)

class DYP_A01 {
public:
  void readSensor();
};

// Declare class globally
DYP_A01 sensor;


/******** Pin, Variables and Class for LoRaWAN Connections **********/
#define MAX_RETRY_CONNECTION 8
#define JOIN_RETRY_DELAY_MINUTES 2 
#define JOIN_RETRY_SLEEP_MINUTES 30 // Rejoin LoRa Network in the next 30 minutes
#define LORA_CONNECTION_STABILIZATION_DELAY_SECONDS 5 // Stabilize LoRa connections

// Payload in CayenneLPP Format
byte payload[10];

// Class for LoRaWAN Connection
class LoRaWAN {
public:
  LoRaModem modem;
  String appEui = SECRET_APP_EUI;
  String appKey = SECRET_APP_KEY;
  uint16_t packetCount = 0;

  void init();
  void executeDownlink();
  void sendData(byte* payload, size_t payloadSize);
};

// Declare class globally
LoRaWAN lorawan;

/******** Class and Function for Power Management **********/
class PowerManagement {
public:
  void enablePowerSavingMode();
};

// Declare class globally
PowerManagement powerManagement;

/******** Class for Battery Monitoring **********/
class BatteryMonitor {
public:
  Adafruit_MAX17048 maxlipo;
  void begin();
  void readBattery();
  void powerOff();
  void powerOn();
};

// Declare class globally
BatteryMonitor batteryMonitor;

void setup() {
  // Enable power-saving mode
  powerManagement.enablePowerSavingMode();

  // Start the serial communication with the sensor and the serial monitor
  Serial.begin(9600);   // Serial monitor
  Serial1.begin(9600);  // Serial1 for hardware serial communication with the sensor
  Serial.println("Ultrasonic Sensor UART Test");

  // Initialize LoRaWAN Connections
  lorawan.init();

  // Initialize Battery Monitor
  //batteryMonitor.begin();

  // Set pin modes for charge controller with pull-up resistors
  // pinMode(PGOOD_PIN, INPUT_PULLUP);
  // pinMode(CHG_PIN, INPUT_PULLUP);

  // Attach wakeup function to handle wakeup event
  //LowPower.attachInterruptWakeup(RTC_ALARM_WAKEUP, wakeup, CHANGE);
}


void loop() {
  sensor.readSensor();
  //batteryMonitor.powerOn();
  //batteryMonitor.readBattery();
  //batteryMonitor.powerOff();
  
  printPayload(payload, sizeof(payload));

  lorawan.sendData(payload, sizeof(payload));
  lorawan.executeDownlink();

  // Put the board to sleep for the defined interval
  LowPower.deepSleep(interval);
}

void LoRaWAN::init() {
  int joinAttempts = 0;
    // Initialize LoRa module
  if (!modem.begin(EU868)) {
    Serial.println("Failed to start module");
    while (1) {}
  }
  Serial.print("Your module version is: ");
  Serial.println(modem.version());
  Serial.print("Your device EUI is: ");
  Serial.println(modem.deviceEUI());

  // Join the network
  int connected = modem.joinOTAA(appEui, appKey);

  // Attempt to reconnect to LoRa
  while (!connected && joinAttempts < MAX_JOIN_ATTEMPTS) {
    joinAttempts++;
    Serial.println("Not connected, trying again...");
    delay(JOIN_RETRY_DELAY_MINUTES * 60 * 1000);  // wait before next attempt
    connected = modem.joinOTAA(appEui, appKey);
  }

  if (connected) {
    Serial.println("Successfully joined the network");
  } else {
    Serial.println("Failed to join network after several attempts. The device is going into a low power mode before trying again.");
    LowPower.sleep(JOIN_RETRY_SLEEP_MINUTES * 60 * 1000);  // sleep
    init();  // try to initialize the LoRaWAN connection again
  }

  modem.setADR(true);
  modem.minPollInterval(60);
  delay(LORA_CONNECTION_STABILIZATION_DELAY_SECONDS * 1000);  // wait to stabilize connection
}

void LoRaWAN::executeDownlink() {
  if (!modem.available()) {
    Serial.println("No downlink message received at this time.");
    return;
  }
  char rcv[64];
  int i = 0;
  while (modem.available()) {
    rcv[i++] = (char)modem.read();
  }

  rcv[i] = '\0'; // Null-terminate the string

  Serial.print("Received: ");
  for (unsigned int j = 0; j < i; j++) {
    Serial.print(rcv[j] >> 4, HEX);
    Serial.print(rcv[j] & 0xF, HEX);
    Serial.print(" ");
  }
  Serial.println();

  // Check if the received command is "1"
  if (rcv[0] == 0x01) {
    Serial.println("Received reset command, sending reset payload and resetting the board.");
    
    // Prepare reset payload
    byte resetPayload[4] = { 'R', 'E', 'S', 'T' };

    // Send reset payload
    sendData(resetPayload, sizeof(resetPayload));

    // Delay to ensure the payload is sent
    delay(1000);

    // Reset the board
    NVIC_SystemReset();
  } else {
      Serial.println("No valid reset command received.");
    }
}

void LoRaWAN::sendData(byte* payload, size_t payloadSize) {
  int err;
  modem.beginPacket();
  modem.write(payload, payloadSize);
  err = modem.endPacket(true);

  if (err > 0) {
    packetCount++;
    Serial.println("LoRa Packet sent");
  } else {
    Serial.println("Error sending LoRa Packet");
  }
  delay(1000);
}

void DYP_A01::readSensor() {
  // Turn on the sensor by setting the MOSFET gate HIGH
  Serial.println("Turning on the sensor...");
  //digitalWrite(sensorPowerPin, HIGH);

  delay(2000); // Wait for the sensor to power up

  // Clear the serial buffer
  while (Serial1.available()) {
    Serial1.read();
  }

  // Send a trigger pulse
  Serial1.write(0x55); // Sending any data to trigger the sensor

  // Wait for the response with a timeout mechanism
  unsigned long responseTimeout = millis() + 100; // 100ms timeout
  bool sensorDataReceived = false;
  int distance = -1;

  while (millis() < responseTimeout) {
    if (Serial1.available()) {
      // Read the frame header
      if (Serial1.read() == 0xFF) {
        // Ensure enough data is available
        while (Serial1.available() < 3 && millis() < responseTimeout) {
          // Wait for the remaining data to be available
        }

        if (Serial1.available() >= 3) {
          // Read the next three bytes
          byte Data_H = Serial1.read();
          byte Data_L = Serial1.read();
          byte SUM = Serial1.read();

          // Verify checksum
          byte calculatedSUM = (0xFF + Data_H + Data_L) & 0xFF;
          if (calculatedSUM == SUM) {
            // Calculate distance
            distance = (Data_H << 8) + Data_L;
            Serial.print("Distance: ");
            Serial.print(distance);
            Serial.println(" mm");
            sensorDataReceived = true;
          } else {
            Serial.println("Checksum error");
          }
        } else {
          Serial.println("Timeout waiting for full data packet");
        }
        break; // Exit the loop after reading data
      }
    }
  }

  if (!sensorDataReceived) {
    Serial.println("No sensor data received");
  }

  // Turn off the sensor to save power
  Serial.println("Turning off the sensor...");
  digitalWrite(sensorPowerPin, LOW);

  // Update and print device health status
  deviceHealth.updateDeviceHealth();
  deviceHealth.printDeviceHealth();

  // Construct the status byte into CayenneLPP format
  int batteryVoltageMilliVolts = deviceHealth.batteryVoltage * 1000;
  int batteryPercentageHundredths = deviceHealth.batteryPercentage * 100;

  payload[0] = highByte(distance);
  payload[1] = lowByte(distance);
  payload[2] = deviceHealth.battery_status;
  payload[3] = deviceHealth.solar_status;
  payload[4] = highByte(lorawan.packetCount);
  payload[5] = lowByte(lorawan.packetCount);
  payload[6] = highByte(batteryVoltageMilliVolts); // Convert voltage to mV
  payload[7] = lowByte(batteryVoltageMilliVolts);
  payload[8] = highByte(batteryPercentageHundredths); // Convert percentage to 0.01%
  payload[9] = lowByte(batteryPercentageHundredths);
}


// Function to update the status of the solar panel and battery
void DeviceHealth::updateDeviceHealth() {
  int pgood_count = 0;
  int chg_count = 0;

  // Take multiple samples to determine status
  for (int i = 0; i < CHARGE_SAMPLES; i++) {
    int pgood_value = digitalRead(PGOOD_PIN);
    int chg_value = digitalRead(CHG_PIN);
    
    // Debug prints for pin values
    Serial.print("Sample ");
    Serial.print(i);
    Serial.print(" - PGOOD_PIN value: ");
    Serial.println(pgood_value);
    Serial.print("Sample ");
    Serial.print(i);
    Serial.print(" - CHG_PIN value: ");
    Serial.println(chg_value);

    pgood_count += (pgood_value == LOW) ? 1 : 0;
    chg_count += (chg_value == LOW) ? 1 : 0;
    delay(SAMPLE_DELAY);
  }

  // Debugging counts
  Serial.print("PGOOD count: ");
  Serial.println(pgood_count);
  Serial.print("CHG count: ");
  Serial.println(chg_count);

  // Determine battery status
  if (chg_count > CHARGE_SAMPLES / 2) {
    battery_status = CHARGING;
    solar_status = ACTIVE;  // Consider solar panel active if charging
  } else if (pgood_count > CHARGE_SAMPLES / 2) {
    solar_status = ACTIVE;
    battery_status = FULL;  // Assume battery is full if not charging but solar is active
  } else {
    solar_status = OFF;
    battery_status = DRAINING;
  }

  // Read battery voltage and percentage from MAX17048
  batteryVoltage = batteryMonitor.maxlipo.cellVoltage();
  batteryPercentage = batteryMonitor.maxlipo.cellPercent();

  // Debug output for final status
  Serial.println(solar_status == ACTIVE ? "Solar panel is ACTIVE." : "Solar panel is OFF.");
  switch (battery_status) {
    case CHARGING:
      Serial.println("Battery is CHARGING.");
      break;
    case FULL:
      Serial.println("Battery is FULL.");
      break;
    case DRAINING:
      Serial.println("Battery is DRAINING.");
      break;
  }
  Serial.print("Battery Voltage: ");
  Serial.print(batteryVoltage);
  Serial.println(" V");
  Serial.print("Battery Percentage: ");
  Serial.print(batteryPercentage);
  Serial.println(" %");
  Serial.println();
}






// Function to print the current status of the solar panel and battery
void DeviceHealth::printDeviceHealth() {
  // Print solar panel status
  if (solar_status == ACTIVE) {
    Serial.println("Solar panel is ACTIVE.");
  } else {
    Serial.println("Solar panel is OFF.");
  }

  // Print battery status
  switch (battery_status) {
    case CHARGING:
      Serial.println("Battery is CHARGING.");
      break;
    case FULL:
      Serial.println("Battery is FULL.");
      break;
    case DRAINING:
      Serial.println("Battery is DRAINING.");
      break;
  }

  // Print battery voltage and percentage
  Serial.print("Battery Voltage: ");
  Serial.print(batteryVoltage);
  Serial.println(" V");

  Serial.print("Battery Percentage: ");
  Serial.print(batteryPercentage);
  Serial.println(" %");

  // Print a blank line for readability
  Serial.println();
}

// Function to print the payload array in hexadecimal format
void printPayload(byte* payload, size_t payloadSize) {
  Serial.print("Payload: ");
  for (size_t i = 0; i < payloadSize; i++) {
    if (payload[i] < 0x10) {
      Serial.print("0");
    }
    Serial.print(payload[i], HEX);
    if (i < payloadSize - 1) {
      Serial.print(" ");
    }
  }
  Serial.println();
}

void wakeup() {
  // This function will be called when the microcontroller wakes up
  // Re-enable peripherals if needed
  // Serial.begin(9600);   // Serial monitor
  // Serial1.begin(9600);  // Serial1 for hardware serial communication with the sensor
  //Serial.println("Woke up from sleep");
}

void PowerManagement::enablePowerSavingMode() {
  // Set digital pins to input
  for (int pin = 0; pin < 12; pin++) {
    pinMode(pin, INPUT);
    digitalWrite(pin, LOW);
  }

  // Disable ADC
  ADC->CTRLA.bit.ENABLE = 0;
  while (ADC->STATUS.bit.SYNCBUSY);

  // Disable DAC
  DAC->CTRLA.bit.ENABLE = 0;
  while (DAC->STATUS.bit.SYNCBUSY);

  // Disable SERCOM4
  SERCOM4->USART.CTRLA.bit.ENABLE = 0;
  while (SERCOM4->USART.SYNCBUSY.bit.ENABLE);

  // Initialize the sensor power pin
  pinMode(sensorPowerPin, OUTPUT);
  digitalWrite(sensorPowerPin, LOW); // Ensure the sensor is off initially

  // Initialize the charge controller pins
  // pinMode(PGOOD_PIN, OUTPUT);
  // pinMode(CHG_PIN, OUTPUT);
  digitalWrite(PGOOD_PIN, LOW);
  digitalWrite(CHG_PIN, LOW);

  //USBDevice.detach();
}

void BatteryMonitor::begin() {
  pinMode(11, OUTPUT);
  pinMode(12, OUTPUT);
  digitalWrite(11, LOW);
  digitalWrite(12, LOW);

  if (!maxlipo.begin()) {
    Serial.println(F("Could not find Adafruit MAX17048. Please check wiring!"));
    while (1) delay(10);
  }
  Serial.print(F("Found MAX17048 with Chip ID: 0x")); 
  Serial.println(maxlipo.getChipID(), HEX);
}

void BatteryMonitor::readBattery() {
  float voltage = maxlipo.cellVoltage();
  float percentage = maxlipo.cellPercent();

  if (isnan(voltage) || isnan(percentage)) {
    Serial.println("Failed to read from MAX17048, check the battery connection!");
  } else {
    deviceHealth.batteryVoltage = voltage;
    deviceHealth.batteryPercentage = percentage;
  }
}

void BatteryMonitor::powerOff() {
  digitalWrite(11, LOW);
  digitalWrite(12, LOW);
  Serial.println("Battery monitor powered off.");
}

void BatteryMonitor::powerOn() {
  digitalWrite(11, HIGH);
  digitalWrite(12, HIGH);
  Serial.println("Battery monitor powered on.");
  delay(500);}

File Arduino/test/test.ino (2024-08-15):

#include <Wire.h>
#include <Adafruit_GFX.h>
#include <Adafruit_SSD1306.h>
#include <SPI.h>
#include <SD.h>

// SD card chip select pin
//const int chipSelect = 5;

// OLED screen parameters
//#define SCREEN_WIDTH 128 // OLED display width, in pixels
//#define SCREEN_HEIGHT 32 // OLED display height, in pixels

// Declaration for an SSD1306 display connected to I2C (SDA, SCL pins)
//Adafruit_SSD1306 display(SCREEN_WIDTH, SCREEN_HEIGHT, &Wire, -1);

// Ultrasonic sensor interval
const unsigned long sensorInterval = 6000;  // 10 seconds
unsigned long previousMillis = 0;

// Global variable to store distance
int distance = -1;

// Function to initialize OLED display
// void setupOLED() {
//   if (!display.begin(SSD1306_SWITCHCAPVCC, 0x3C)) { // Address 0x3C for 128x32
//     Serial.println(F("SSD1306 allocation failed"));
//     for (;;); // Don't proceed, loop forever
//   }
//   display.clearDisplay();
//   display.setTextSize(1);      // Set text size
//   display.setTextColor(WHITE); // Set text color
//   display.display();           // Display the initialized screen
// }

// Function to print data to OLED
// void printDataToOLED(String dataString) {
//   display.clearDisplay();
//   display.setCursor(0, 10);
//   display.setTextSize(1);  // Ensure text size is set
//   display.println(dataString);
//   display.display(); // Update the display with new content
// }

// Function to write data to SD card
// void writeDataToSD(String dataString) {
//   File dataFile = SD.open("datalog.txt", FILE_WRITE);
//   if (dataFile) {
//     dataFile.println(dataString);
//     dataFile.close();
//     Serial.println("Data written to SD card.");
//   } else {
//     Serial.println("Error opening datalog.txt");
//   }
// }

// Ultrasonic sensor read function
void readSensor() {
  ///delay(500); // Wait for the sensor to power up

  // Clear the serial buffer
  while (Serial1.available()) {
    Serial1.read();
  }

  // Send a trigger pulse
  Serial1.write(0x55);  // Sending any data to trigger the sensor

  // Wait for the response with a timeout mechanism
  unsigned long responseTimeout = millis() + 100;  // 100ms timeout
  bool sensorDataReceived = false;
  distance = -1;

  while (millis() < responseTimeout) {
    if (Serial1.available()) {
      // Read the frame header
      if (Serial1.read() == 0xFF) {
        // Ensure enough data is available
        while (Serial1.available() < 3 && millis() < responseTimeout) {
          // Wait for the remaining data to be available
        }

        if (Serial1.available() >= 3) {
          // Read the next three bytes
          byte Data_H = Serial1.read();
          byte Data_L = Serial1.read();
          byte SUM = Serial1.read();

          // Verify checksum
          byte calculatedSUM = (0xFF + Data_H + Data_L) & 0xFF;
          if (calculatedSUM == SUM) {
            // Calculate distance
            distance = (Data_H << 8) + Data_L;
            Serial.print("Distance: ");
            Serial.print(distance);
            Serial.println(" mm");
            sensorDataReceived = true;
          } else {
            Serial.println("Checksum error");
          }
        } else {
          Serial.println("Timeout waiting for full data packet");
        }
        break;  // Exit the loop after reading data
      }
    }
  }

  if (!sensorDataReceived) {
    Serial.println("No sensor data received");
  }
}

void setup() {
  // Open serial communications and wait for port to open:
  Serial.begin(9600);
  Serial1.begin(9600);  // Initialize Serial1 for the sensor

  //setupOLED(); // Initialize OLED display

  //Serial.print("Initializing SD card...");

  // see if the card is present and can be initialized:
  //   if (!SD.begin(chipSelect)) {
  //     Serial.println("Card failed, or not present");
  //     // don't do anything more:
  //     while (1);
  //   }
  //   Serial.println("Card initialized.");
  // }

  void loop() {
    unsigned long currentMillis = millis();
    if (currentMillis - previousMillis >= sensorInterval) {
      previousMillis = currentMillis;

      readSensor();

      // if (distance != -1) { // Check if valid distance is read
      //   String dataString = "Distance=" + String(distance) + " mm";
      //   printDataToOLED(dataString);
      //   writeDataToSD(dataString);
    

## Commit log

2024-05-22 initial commit for adafruit DYP A01 ultrasonic sensor
2024-05-26 remove serial print each second
2024-05-26 fix arduino secrets
2024-05-30 Update sensor reading
2024-06-10 add mosfets to switch on off sensor
2024-06-12 uncomment power saving mode
2024-06-12 add function to monitor solar charger
2024-06-12 create functions to read sensor
2024-06-12 fix the payload message
    [DYP-A01.ino]
2024-06-12 fix the payload for solar charger
    [DYP-A01.ino]
2024-06-12 create function to conserve power
2024-06-19 try to fix downlink function to reset board
    [DYP-A01.ino]
2024-07-03 upload schematics and board eagle files
    [water_height_monitoring_system v12.brd, water_height_monitoring_system_v1.sch]
2024-07-03 upload gerber files
    [copper_bottom.gbr, copper_top.gbr, drill_1_16.xln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]
2024-07-03 upload enclosure model
    [bot_part_v1.stl, top_part_v1.stl]
2024-07-03 upload calibrator code
2024-07-03 update calibration mode
2024-07-11 fix charging logic
2024-08-15 fix files didnt commited properly
    [Body1.stl, StraightTwoScrews.stl, arm.stl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]
2024-08-23 add dissertation data
    [batt voltage.csv, battery calculation.xlsx, comparison data.csv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]
2024-08-30 upload readme files
    [back_bracket v1.stl, back_bracket_v2.stl, device_bracket.stl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]

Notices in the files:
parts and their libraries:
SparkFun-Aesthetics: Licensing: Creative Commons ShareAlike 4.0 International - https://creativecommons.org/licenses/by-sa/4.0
